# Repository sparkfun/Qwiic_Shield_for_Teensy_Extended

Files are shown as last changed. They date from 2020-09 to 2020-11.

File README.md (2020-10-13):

SparkFun Qwiic Shield for Teensy - Extended
========================================

SparkFun Qwiic Shield for Teensy

[SparkFun Qwiic Shield for Teensy (DEV-17156)](https://www.sparkfun.com/products/17156)

The SparkFun Qwiic Shield for Teensy connects the I<sup>2</sup>C bus on a Teensy-extended footprint (Teensy 4.1, 3.6, 3.5) to four Qwiic connectors as well as a "PROG" button in parallel with the Program button on the Teensy development board for easy access. The shield includes a set of headers to solder to the shield for connection to the Teensy.

Repository Contents
-------------------

* **/Documentation** - Board schematic (PDF) and dimensions (PNG & PDF)
* **/Hardware** - Eagle design files (.brd, .sch)

Documentation
--------------
* **[Hookup Guide](https://learn.sparkfun.com/tutorials/sparkfun-qwiic-shield-for-teensy-hookup-guide)** - Basic hookup guide for the SparkFun Qwiic Shield for Teensy - Extended

Version History
---------------
* **[DEV-17156](https://www.sparkfun.com/products/17156)** - Initial release.

License Information
-------------------

This product is _**open source**_! 

Please review the LICENSE.md file for license information. 

If you have any questions or concerns on licensing, please contact technical support on our [SparkFun forums](https://forum.sparkfun.com/viewforum.php?f=152).

Distributed as-is; no warranty is given.

- Your friends at SparkFun.

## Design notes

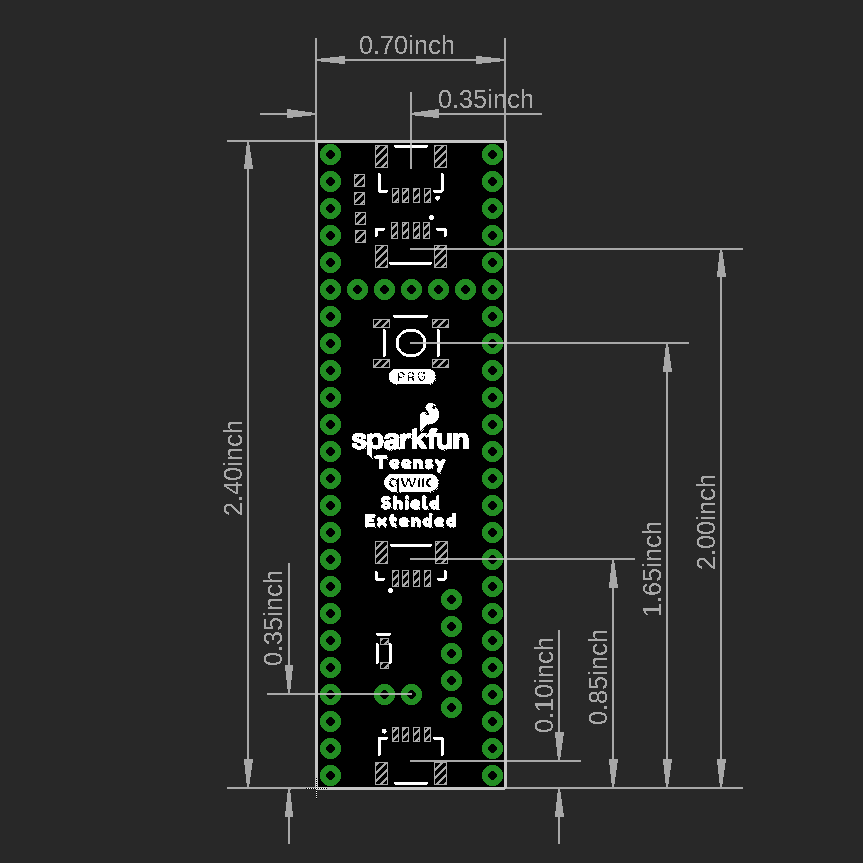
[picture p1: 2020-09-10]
Documents/Qwiic_Shield_for_Teensy_Extended_Dimensions.png

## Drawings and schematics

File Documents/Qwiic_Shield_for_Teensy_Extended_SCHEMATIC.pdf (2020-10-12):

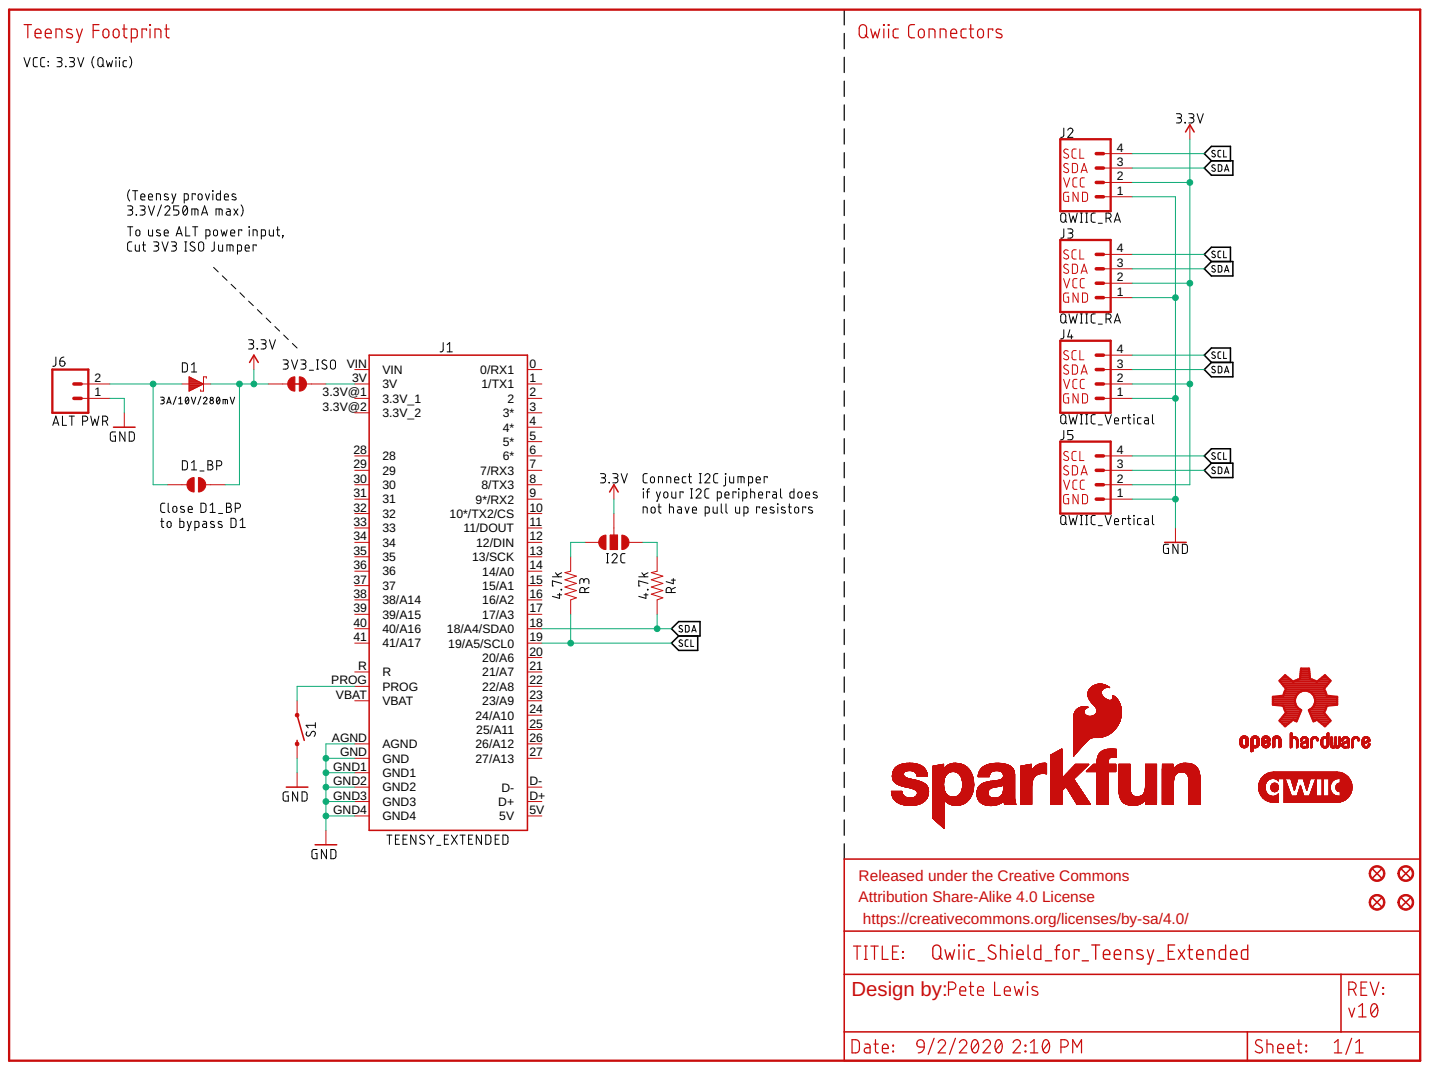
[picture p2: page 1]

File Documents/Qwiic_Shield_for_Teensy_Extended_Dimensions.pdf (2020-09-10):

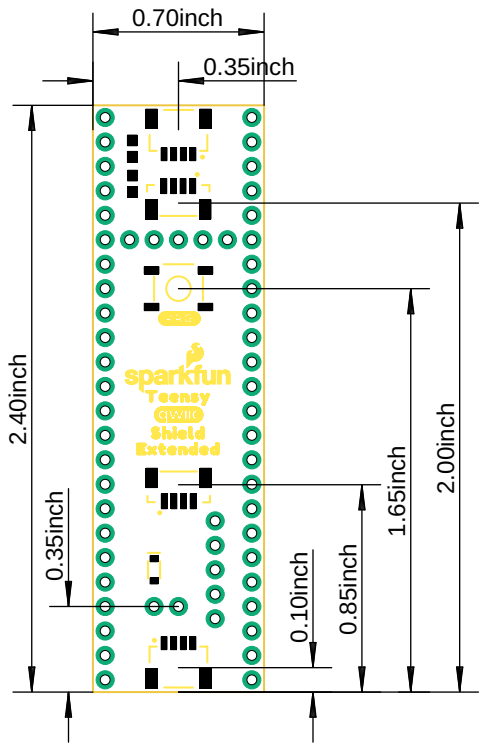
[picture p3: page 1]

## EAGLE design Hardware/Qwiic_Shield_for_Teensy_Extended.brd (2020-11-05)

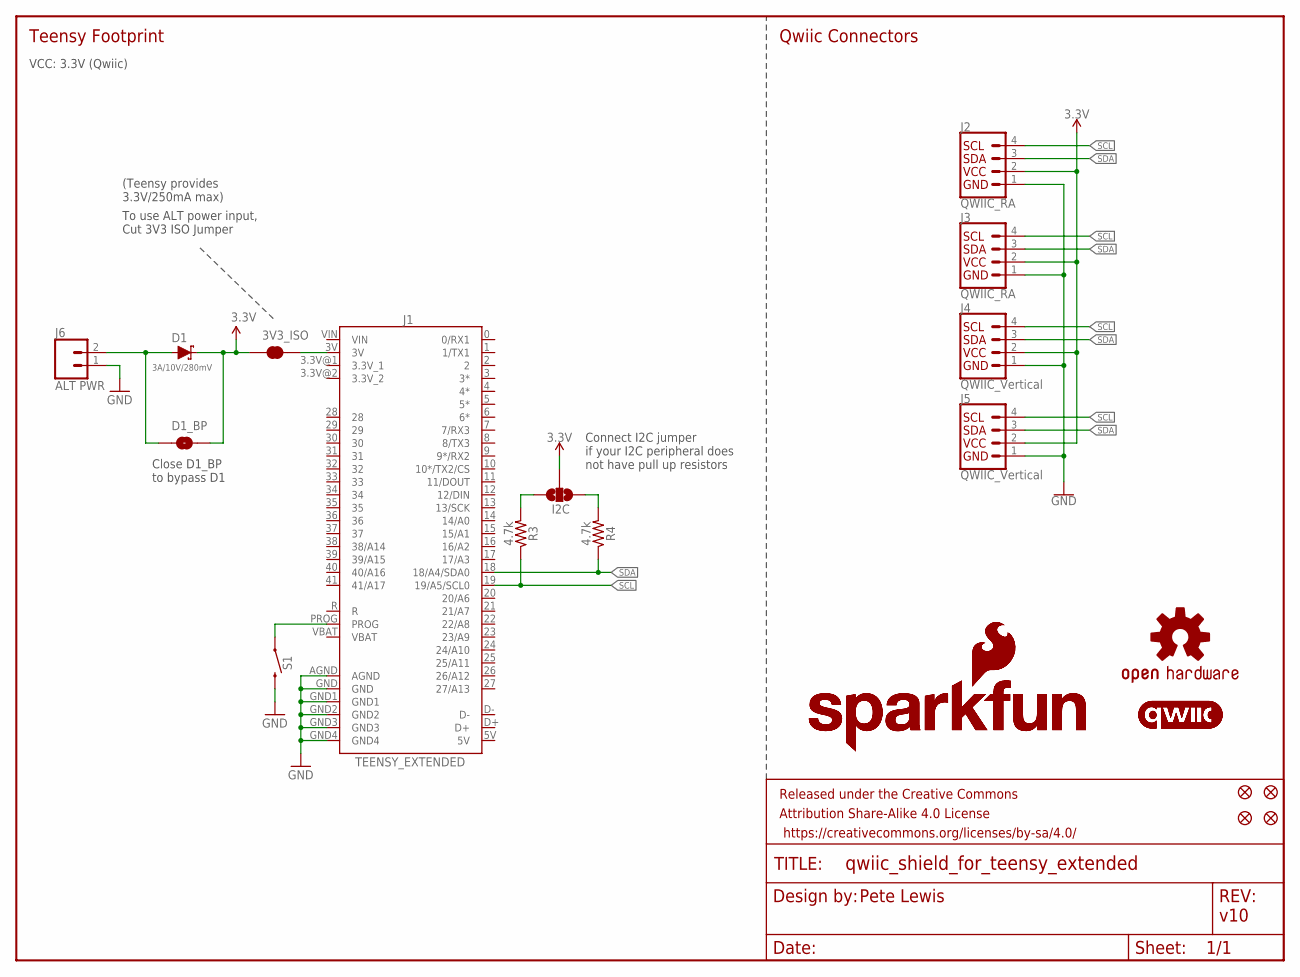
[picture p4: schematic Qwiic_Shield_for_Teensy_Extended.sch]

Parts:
3V3_ISO: JUMPER-SMT_2_NC_TRACE_SILK; SMT-JUMPER_2_NC_TRACE_SILK
D1: 3A/10V/280mV; SOD-323
D1_BP: JUMPER-SMT_2_NO_SILK; SMT-JUMPER_2_NO_SILK
FD1, FD2, FD3, FD4: FIDUCIAL1X2; FIDUCIAL-1X2
FRAME1: FRAME-LETTER; CREATIVE_COMMONS
I2C: JUMPER-SMT_3_NO_SILK; SMT-JUMPER_3_NO_SILK
J1: TEENSY_EXTENDED; TEENSY_EXTENDED_NO_SILK
J2, J3: QWIIC_RA; JST04_1MM_RA
J4, J5: QWIIC_Vertical; JST04_1MM_VERT
J6: ALT PWR; 1X02_NO_SILK
LOGO1, LOGO2: SFE_LOGO_NAME_FLAME.1_INCH; SFE_LOGO_NAME_FLAME_.1
LOGO3: OSHW-LOGOS; OSHW-LOGO-S
LOGO4, LOGO5: QWIIC_LOGO_5MM; QWIIC_5MM
R3, R4: 4.7k; 0603
S1: SMD_5.2MM; TACTILE_SWITCH_SMD_5.2MM

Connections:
3.3V: 3V3_ISO.1, D1.C, D1_BP.2, I2C.2, J2.2, J3.2, J4.2, J5.2
3.3V_1: J1.3.3V@1 (3.3V_1)
3.3V_2: J1.3.3V@2 (3.3V_2)
5V: J1.5V
D+: J1.D+
D-: J1.D-
GND: J1.AGND, J1.GND, J1.GND1, J1.GND2, J1.GND3, J1.GND4, J2.1, J3.1, J4.1, J5.1, J6.1, S1.3 (2)
unnamed: I2C.3, R4.2
unnamed: I2C.1, R3.2
unnamed: 3V3_ISO.2, J1.3V
unnamed: D1.A, D1_BP.1, J6.2
unnamed: J1.PROG, S1.1
SCL: J1.19 (19/A5/SCL0), J2.4, J3.4, J4.4, J5.4, R3.1
SDA: J1.18 (18/A4/SDA0), J2.3, J3.3, J4.3, J5.3, R4.1
VBAT: J1.VBAT
VIN: J1.VIN

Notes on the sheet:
Pete Lewis
v10
Teensy Footprint
Qwiic Connectors
VCC: 3.3V (Qwiic)
(Teensy provides 3.3V/250mA max)
Connect I2C jumper if your I2C peripheral does not have pull up resistors
To use ALT power input, Cut 3V3 ISO Jumper
Close D1_BP to bypass D1

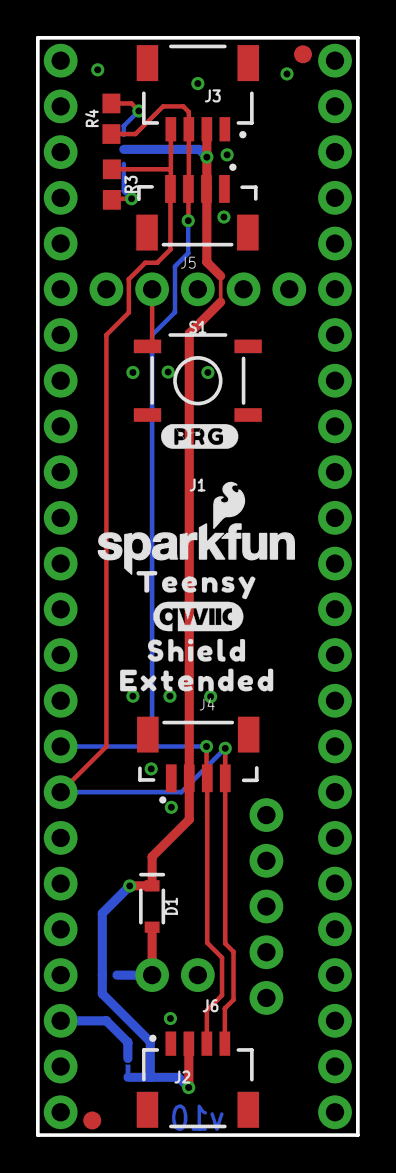
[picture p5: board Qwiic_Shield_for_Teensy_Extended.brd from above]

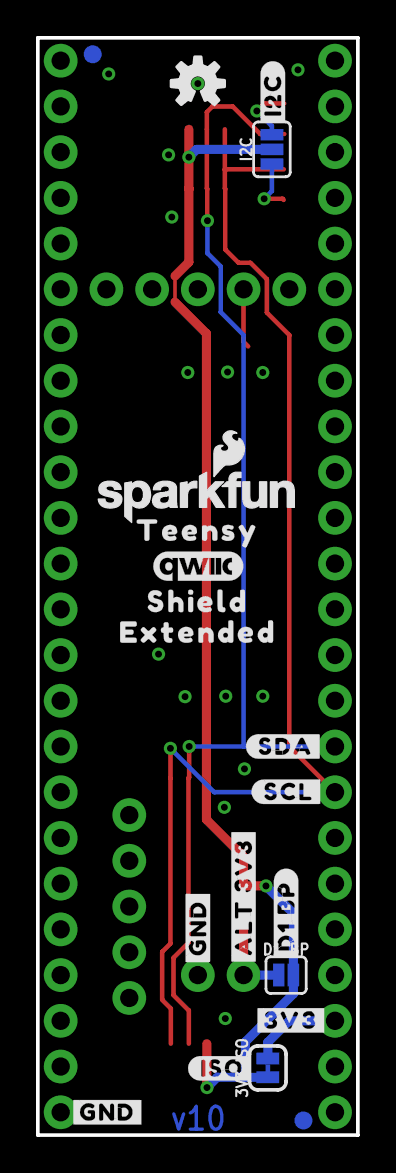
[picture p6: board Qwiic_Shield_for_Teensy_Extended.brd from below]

Board: 2 copper layers, 17.8 x 61.0 mm, 40 parts (20 on the bottom side), 9 nets.

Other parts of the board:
U$1: #I2C#0
U$2, U$13: TEENSY0
U$3: 3V36
U$4: #D1_BP#0
U$5: #ALT_3V3#0
U$6: #PRG#0
U$7, U$9: #GND#0
U$8, U$12: SHIELD0
U$10: #ISO#0
U$11, U$16: EXTENDED0
U$15: #3V3#0
U$18: #SDA#0
U$19: #SCL#0

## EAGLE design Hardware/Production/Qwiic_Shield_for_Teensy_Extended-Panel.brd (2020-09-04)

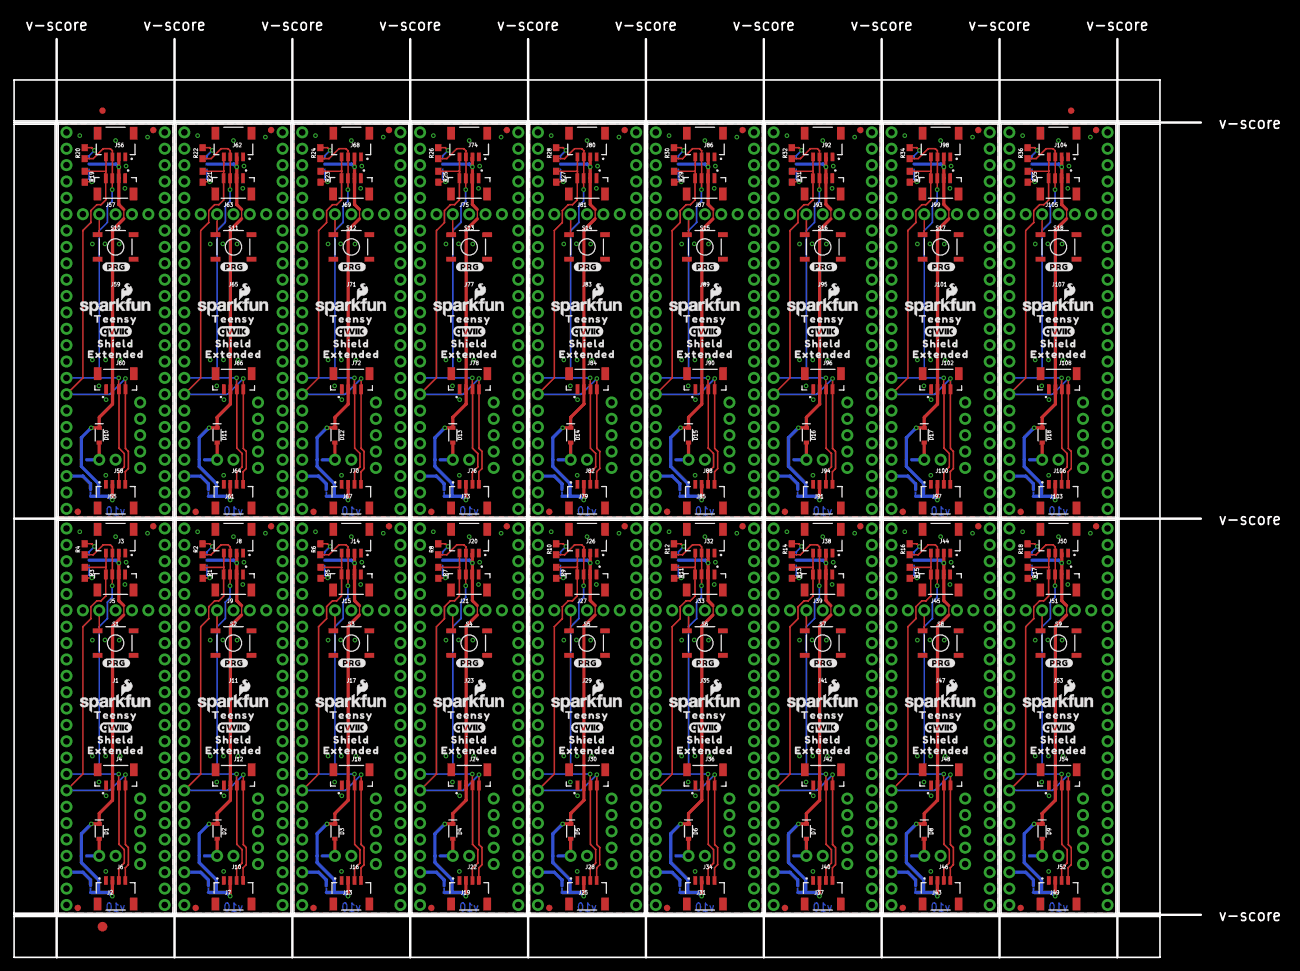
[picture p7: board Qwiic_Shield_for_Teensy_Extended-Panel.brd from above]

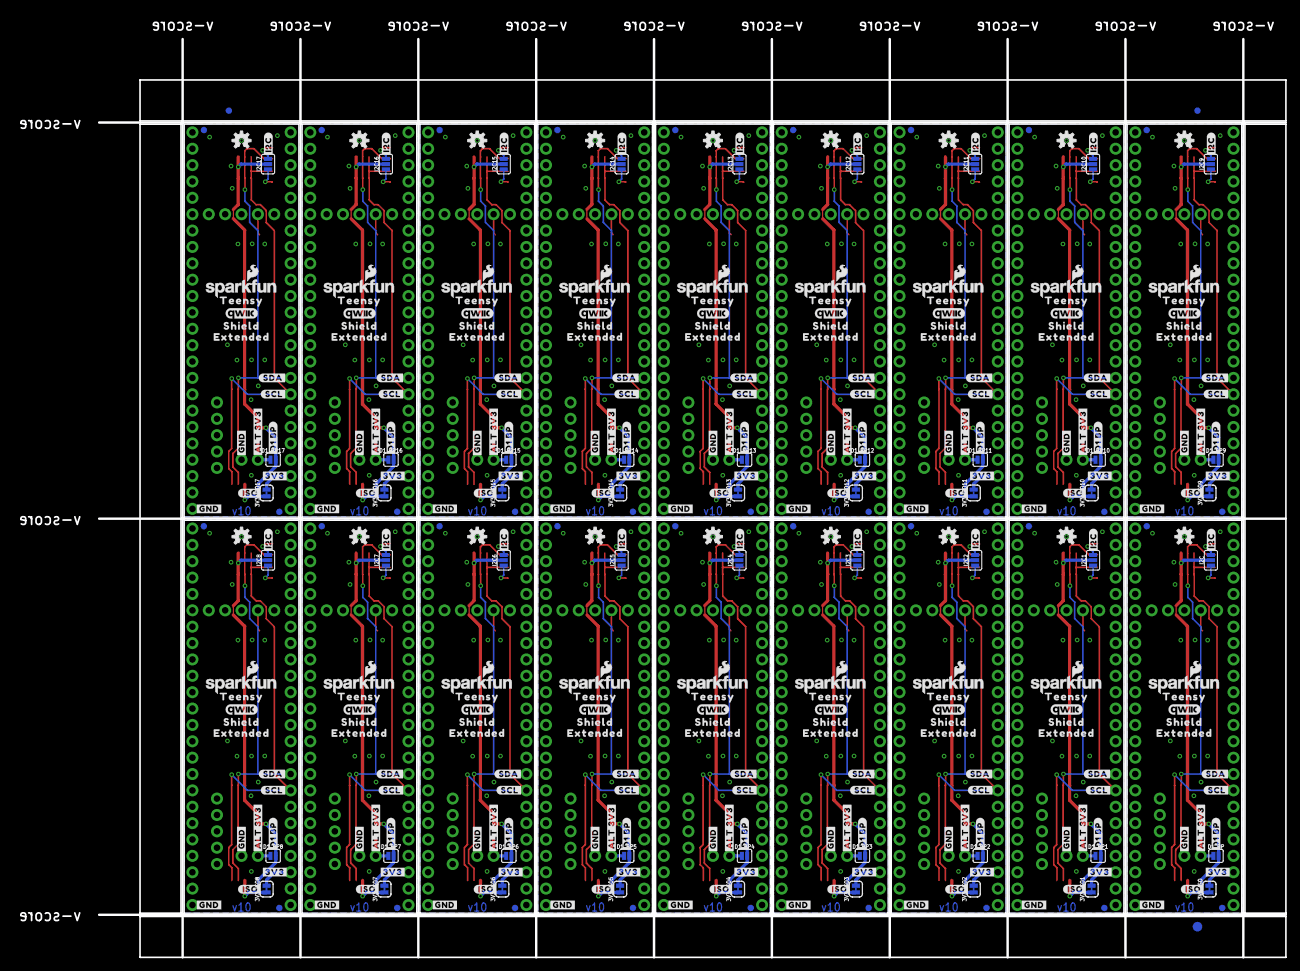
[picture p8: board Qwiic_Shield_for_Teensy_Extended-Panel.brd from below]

Board: 2 copper layers, 184.2 x 142.5 mm, 708 parts (363 on the bottom side), 162 nets.

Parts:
3V3_ISO, 3V3_ISO1, 3V3_ISO2, 3V3_ISO3, 3V3_ISO4, 3V3_ISO5, 3V3_ISO6, 3V3_ISO7, 3V3_ISO8, 3V3_ISO9, 3V3_ISO10, 3V3_ISO11, 3V3_ISO12, 3V3_ISO13, 3V3_ISO14, 3V3_ISO15, 3V3_ISO16, 3V3_ISO17: SMT-JUMPER_2_NC_TRACE_SILK
D1, D2, D3, D4, D5, D6, D7, D8, D9, D10, D11, D12, D13, D14, D15, D16, D17, D18: 3A/10V/280mV; SOD-323
D1_BP, D1_BP1, D1_BP2, D1_BP3, D1_BP4, D1_BP5, D1_BP6, D1_BP7, D1_BP8, D1_BP9, D1_BP10, D1_BP11, D1_BP12, D1_BP13, D1_BP14, D1_BP15, D1_BP16, D1_BP17: SMT-JUMPER_2_NO_SILK
E$1, E$2, E$3, E$4: FIDUCIAL-1X2
E$5, E$6: FIDUCIAL-1.5X3
FD1, FD2, FD3, FD4, FD5, FD6, FD7, FD8, FD9, FD10, FD11, FD12, FD13, FD14, FD15, FD16, FD17, FD18, FD19, FD20, FD21, FD22, FD23, FD24, FD25, FD26, FD27, FD28, FD29, FD30, FD31, FD32, FD33, FD34, FD35, FD36, FD37, FD38, FD39, FD40, FD41, FD42, FD43, FD44, FD45, FD46, FD47, FD48, FD49, FD50, FD51, FD52, FD53, FD54, FD55, FD56, FD57, FD58, FD59, FD60, FD61, FD62, FD63, FD64, FD65, FD66, FD67, FD68, FD69, FD70, FD71, FD72: FIDUCIAL1X2; FIDUCIAL-1X2
I2C, I2C1, I2C2, I2C3, I2C4, I2C5, I2C6, I2C7, I2C8, I2C9, I2C10, I2C11, I2C12, I2C13, I2C14, I2C15, I2C16, I2C17: JUMPER-SMT_3_NO_SILK; SMT-JUMPER_3_NO_SILK
J1, J11, J17, J23, J29, J35, J41, J47, J53, J59, J65, J71, J77, J83, J89, J95, J101, J107: TEENSY_EXTENDED; TEENSY_EXTENDED_NO_SILK
J2, J3, J7, J8, J13, J14, J19, J20, J25, J26, J31, J32, J37, J38, J43, J44, J49, J50, J55, J56, J61, J62, J67, J68, J73, J74, J79, J80, J85, J86, J91, J92, J97, J98, J103, J104: QWIIC_RA; JST04_1MM_RA
J4, J5, J9, J12, J15, J18, J21, J24, J27, J30, J33, J36, J39, J42, J45, J48, J51, J54, J57, J60, J63, J66, J69, J72, J75, J78, J81, J84, J87, J90, J93, J96, J99, J102, J105, J108: QWIIC_Vertical; JST04_1MM_VERT
J6, J10, J16, J22, J28, J34, J40, J46, J52, J58, J64, J70, J76, J82, J88, J94, J100, J106: ALT PWR; 1X02_NO_SILK
LOGO1, LOGO2, LOGO6, LOGO9, LOGO11, LOGO14, LOGO16, LOGO19, LOGO21, LOGO24, LOGO26, LOGO29, LOGO31, LOGO34, LOGO36, LOGO39, LOGO41, LOGO44, LOGO46, LOGO49, LOGO51, LOGO54, LOGO56, LOGO59, LOGO61, LOGO64, LOGO66, LOGO69, LOGO71, LOGO74, LOGO76, LOGO79, LOGO81, LOGO84, LOGO86, LOGO89: SFE_LOGO_NAME_FLAME.1_INCH; SFE_LOGO_NAME_FLAME_.1
LOGO3, LOGO7, LOGO12, LOGO17, LOGO22, LOGO27, LOGO32, LOGO37, LOGO42, LOGO47, LOGO52, LOGO57, LOGO62, LOGO67, LOGO72, LOGO77, LOGO82, LOGO87: OSHW-LOGOS; OSHW-LOGO-S
LOGO4, LOGO5, LOGO8, LOGO10, LOGO13, LOGO15, LOGO18, LOGO20, LOGO23, LOGO25, LOGO28, LOGO30, LOGO33, LOGO35, LOGO38, LOGO40, LOGO43, LOGO45, LOGO48, LOGO50, LOGO53, LOGO55, LOGO58, LOGO60, LOGO63, LOGO65, LOGO68, LOGO70, LOGO73, LOGO75, LOGO78, LOGO80, LOGO83, LOGO85, LOGO88, LOGO90: QWIIC_LOGO_5MM; QWIIC_5MM
R1, R2, R3, R4, R5, R6, R7, R8, R9, R10, R11, R12, R13, R14, R15, R16, R17, R18, R19, R20, R21, R22, R23, R24, R25, R26, R27, R28, R29, R30, R31, R32, R33, R34, R35, R36: 4.7k; 0603
S1, S2, S3, S4, S5, S6, S7, S8, S9, S10, S11, S12, S13, S14, S15, S16, S17, S18: SMD_5.2MM; TACTILE_SWITCH_SMD_5.2MM
U$1, U$23, U$40, U$57, U$74, U$91, U$108, U$125, U$142, U$159, U$176, U$193, U$210, U$227, U$244, U$261, U$278, U$295: #I2C#0
U$2, U$13, U$17, U$30, U$36, U$47, U$53, U$64, U$70, U$81, U$87, U$98, U$104, U$115, U$121, U$132, U$138, U$149, U$155, U$166, U$172, U$183, U$189, U$200, U$206, U$217, U$223, U$234, U$240, U$251, U$257, U$268, U$274, U$285, U$291, U$302: TEENSY0
U$3, U$14, U$35, U$52, U$69, U$86, U$103, U$120, U$137, U$154, U$171, U$188, U$205, U$222, U$239, U$256, U$273, U$290: 3V36
U$4, U$24, U$41, U$58, U$75, U$92, U$109, U$126, U$143, U$160, U$177, U$194, U$211, U$228, U$245, U$262, U$279, U$296: #D1_BP#0
U$5, U$25, U$42, U$59, U$76, U$93, U$110, U$127, U$144, U$161, U$178, U$195, U$212, U$229, U$246, U$263, U$280, U$297: #ALT_3V3#0
U$6, U$28, U$45, U$62, U$79, U$96, U$113, U$130, U$147, U$164, U$181, U$198, U$215, U$232, U$249, U$266, U$283, U$300: #PRG#0
U$7, U$9, U$26, U$32, U$43, U$49, U$60, U$66, U$77, U$83, U$94, U$100, U$111, U$117, U$128, U$134, U$145, U$151, U$162, U$168, U$179, U$185, U$196, U$202, U$213, U$219, U$230, U$236, U$247, U$253, U$264, U$270, U$281, U$287, U$298, U$304: #GND#0
U$8, U$12, U$27, U$31, U$44, U$48, U$61, U$65, U$78, U$82, U$95, U$99, U$112, U$116, U$129, U$133, U$146, U$150, U$163, U$167, U$180, U$184, U$197, U$201, U$214, U$218, U$231, U$235, U$248, U$252, U$265, U$269, U$282, U$286, U$299, U$303: SHIELD0
U$10, U$29, U$46, U$63, U$80, U$97, U$114, U$131, U$148, U$165, U$182, U$199, U$216, U$233, U$250, U$267, U$284, U$301: #ISO#0
U$11, U$16, U$33, U$34, U$50, U$51, U$67, U$68, U$84, U$85, U$101, U$102, U$118, U$119, U$135, U$136, U$152, U$153, U$169, U$170, U$186, U$187, U$203, U$204, U$220, U$221, U$237, U$238, U$254, U$255, U$271, U$272, U$288, U$289, U$305, U$306: EXTENDED0
U$15, U$20, U$37, U$54, U$71, U$88, U$105, U$122, U$139, U$156, U$173, U$190, U$207, U$224, U$241, U$258, U$275, U$292: #3V3#0
U$18, U$21, U$38, U$55, U$72, U$89, U$106, U$123, U$140, U$157, U$174, U$191, U$208, U$225, U$242, U$259, U$276, U$293: #SDA#0
U$19, U$22, U$39, U$56, U$73, U$90, U$107, U$124, U$141, U$158, U$175, U$192, U$209, U$226, U$243, U$260, U$277, U$294: #SCL#0

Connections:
3.3V: 3V3_ISO.1, D1.C, D1_BP.2, I2C.2, J2.2, J3.2, J4.2, J5.2
3.3V1: 3V3_ISO1.1, D1_BP1.2, D2.C, I2C1.2, J7.2, J8.2, J9.2, J12.2
3.3V2: 3V3_ISO2.1, D1_BP2.2, D3.C, I2C2.2, J13.2, J14.2, J15.2, J18.2
3.3V3: 3V3_ISO3.1, D1_BP3.2, D4.C, I2C3.2, J19.2, J20.2, J21.2, J24.2
3.3V4: 3V3_ISO4.1, D1_BP4.2, D5.C, I2C4.2, J25.2, J26.2, J27.2, J30.2
3.3V5: 3V3_ISO5.1, D1_BP5.2, D6.C, I2C5.2, J31.2, J32.2, J33.2, J36.2
3.3V6: 3V3_ISO6.1, D1_BP6.2, D7.C, I2C6.2, J37.2, J38.2, J39.2, J42.2
3.3V7: 3V3_ISO7.1, D1_BP7.2, D8.C, I2C7.2, J43.2, J44.2, J45.2, J48.2
3.3V8: 3V3_ISO8.1, D1_BP8.2, D9.C, I2C8.2, J49.2, J50.2, J51.2, J54.2
3.3V9: 3V3_ISO9.1, D1_BP9.2, D10.C, I2C9.2, J55.2, J56.2, J57.2, J60.2
3.3V10: 3V3_ISO10.1, D1_BP10.2, D11.C, I2C10.2, J61.2, J62.2, J63.2, J66.2
3.3V11: 3V3_ISO11.1, D1_BP11.2, D12.C, I2C11.2, J67.2, J68.2, J69.2, J72.2
3.3V12: 3V3_ISO12.1, D1_BP12.2, D13.C, I2C12.2, J73.2, J74.2, J75.2, J78.2
3.3V13: 3V3_ISO13.1, D1_BP13.2, D14.C, I2C13.2, J79.2, J80.2, J81.2, J84.2
3.3V14: 3V3_ISO14.1, D1_BP14.2, D15.C, I2C14.2, J85.2, J86.2, J87.2, J90.2
3.3V15: 3V3_ISO15.1, D1_BP15.2, D16.C, I2C15.2, J91.2, J92.2, J93.2, J96.2
3.3V16: 3V3_ISO16.1, D1_BP16.2, D17.C, I2C16.2, J97.2, J98.2, J99.2, J102.2
3.3V17: 3V3_ISO17.1, D1_BP17.2, D18.C, I2C17.2, J103.2, J104.2, J105.2, J108.2
GND: J1.AGND, J1.GND, J1.GND1, J1.GND2, J1.GND3, J1.GND4, J2.1, J3.1, J4.1, J5.1, J6.1, S1.3
GND1: J7.1, J8.1, J9.1, J10.1, J11.AGND, J11.GND, J11.GND1, J11.GND2, J11.GND3, J11.GND4, J12.1, S2.3
GND2: J13.1, J14.1, J15.1, J16.1, J17.AGND, J17.GND, J17.GND1, J17.GND2, J17.GND3, J17.GND4, J18.1, S3.3
GND3: J19.1, J20.1, J21.1, J22.1, J23.AGND, J23.GND, J23.GND1, J23.GND2, J23.GND3, J23.GND4, J24.1, S4.3
GND4: J25.1, J26.1, J27.1, J28.1, J29.AGND, J29.GND, J29.GND1, J29.GND2, J29.GND3, J29.GND4, J30.1, S5.3
GND5: J31.1, J32.1, J33.1, J34.1, J35.AGND, J35.GND, J35.GND1, J35.GND2, J35.GND3, J35.GND4, J36.1, S6.3
GND6: J37.1, J38.1, J39.1, J40.1, J41.AGND, J41.GND, J41.GND1, J41.GND2, J41.GND3, J41.GND4, J42.1, S7.3
GND7: J43.1, J44.1, J45.1, J46.1, J47.AGND, J47.GND, J47.GND1, J47.GND2, J47.GND3, J47.GND4, J48.1, S8.3
GND8: J49.1, J50.1, J51.1, J52.1, J53.AGND, J53.GND, J53.GND1, J53.GND2, J53.GND3, J53.GND4, J54.1, S9.3
GND9: J55.1, J56.1, J57.1, J58.1, J59.AGND, J59.GND, J59.GND1, J59.GND2, J59.GND3, J59.GND4, J60.1, S10.3
GND10: J61.1, J62.1, J63.1, J64.1, J65.AGND, J65.GND, J65.GND1, J65.GND2, J65.GND3, J65.GND4, J66.1, S11.3
GND11: J67.1, J68.1, J69.1, J70.1, J71.AGND, J71.GND, J71.GND1, J71.GND2, J71.GND3, J71.GND4, J72.1, S12.3
GND12: J73.1, J74.1, J75.1, J76.1, J77.AGND, J77.GND, J77.GND1, J77.GND2, J77.GND3, J77.GND4, J78.1, S13.3
GND13: J79.1, J80.1, J81.1, J82.1, J83.AGND, J83.GND, J83.GND1, J83.GND2, J83.GND3, J83.GND4, J84.1, S14.3
GND14: J85.1, J86.1, J87.1, J88.1, J89.AGND, J89.GND, J89.GND1, J89.GND2, J89.GND3, J89.GND4, J90.1, S15.3
GND15: J91.1, J92.1, J93.1, J94.1, J95.AGND, J95.GND, J95.GND1, J95.GND2, J95.GND3, J95.GND4, J96.1, S16.3
GND16: J97.1, J98.1, J99.1, J100.1, J101.AGND, J101.GND, J101.GND1, J101.GND2, J101.GND3, J101.GND4, J102.1, S17.3
GND17: J103.1, J104.1, J105.1, J106.1, J107.AGND, J107.GND, J107.GND1, J107.GND2, J107.GND3, J107.GND4, J108.1, S18.3
unnamed: I2C.3, R4.2
unnamed: I2C.1, R3.2
unnamed: 3V3_ISO.2, J1.3V
unnamed: D1.A, D1_BP.1, J6.2
unnamed: J1.PROG, S1.1
unnamed: I2C1.3, R2.2
unnamed: I2C1.1, R1.2
unnamed: D1_BP1.1, D2.A, J10.2
unnamed: J11.PROG, S2.1
unnamed: 3V3_ISO1.2, J11.3V
unnamed: I2C2.3, R6.2
unnamed: I2C2.1, R5.2
unnamed: D1_BP2.1, D3.A, J16.2
unnamed: J17.PROG, S3.1
unnamed: 3V3_ISO2.2, J17.3V
unnamed: I2C3.3, R8.2
unnamed: I2C3.1, R7.2
unnamed: D1_BP3.1, D4.A, J22.2
unnamed: J23.PROG, S4.1
unnamed: 3V3_ISO3.2, J23.3V
unnamed: I2C4.3, R10.2
unnamed: I2C4.1, R9.2
unnamed: D1_BP4.1, D5.A, J28.2
unnamed: J29.PROG, S5.1
unnamed: 3V3_ISO4.2, J29.3V
unnamed: I2C5.3, R12.2
unnamed: I2C5.1, R11.2
unnamed: D1_BP5.1, D6.A, J34.2
unnamed: J35.PROG, S6.1
unnamed: 3V3_ISO5.2, J35.3V
unnamed: I2C6.3, R14.2
unnamed: I2C6.1, R13.2
unnamed: D1_BP6.1, D7.A, J40.2
unnamed: J41.PROG, S7.1
unnamed: 3V3_ISO6.2, J41.3V
unnamed: I2C7.3, R16.2
unnamed: I2C7.1, R15.2
unnamed: D1_BP7.1, D8.A, J46.2
unnamed: J47.PROG, S8.1
unnamed: 3V3_ISO7.2, J47.3V
unnamed: I2C8.3, R18.2
unnamed: I2C8.1, R17.2
unnamed: D1_BP8.1, D9.A, J52.2
unnamed: J53.PROG, S9.1
unnamed: 3V3_ISO8.2, J53.3V
unnamed: I2C9.3, R20.2
unnamed: I2C9.1, R19.2
unnamed: D1_BP9.1, D10.A, J58.2
unnamed: J59.PROG, S10.1
unnamed: 3V3_ISO9.2, J59.3V
unnamed: I2C10.3, R22.2
unnamed: I2C10.1, R21.2
unnamed: D1_BP10.1, D11.A, J64.2
unnamed: J65.PROG, S11.1
unnamed: 3V3_ISO10.2, J65.3V
unnamed: I2C11.3, R24.2
unnamed: I2C11.1, R23.2
unnamed: D1_BP11.1, D12.A, J70.2
unnamed: J71.PROG, S12.1
unnamed: 3V3_ISO11.2, J71.3V
unnamed: I2C12.3, R26.2
unnamed: I2C12.1, R25.2
unnamed: D1_BP12.1, D13.A, J76.2
unnamed: J77.PROG, S13.1
unnamed: 3V3_ISO12.2, J77.3V
unnamed: I2C13.3, R28.2
unnamed: I2C13.1, R27.2
unnamed: D1_BP13.1, D14.A, J82.2
unnamed: J83.PROG, S14.1
unnamed: 3V3_ISO13.2, J83.3V
unnamed: I2C14.3, R30.2
unnamed: I2C14.1, R29.2
unnamed: D1_BP14.1, D15.A, J88.2
unnamed: J89.PROG, S15.1
unnamed: 3V3_ISO14.2, J89.3V
unnamed: I2C15.3, R32.2
unnamed: I2C15.1, R31.2
unnamed: D1_BP15.1, D16.A, J94.2
unnamed: J95.PROG, S16.1
unnamed: 3V3_ISO15.2, J95.3V
unnamed: I2C16.3, R34.2
unnamed: I2C16.1, R33.2
unnamed: D1_BP16.1, D17.A, J100.2
unnamed: J101.PROG, S17.1
unnamed: 3V3_ISO16.2, J101.3V
unnamed: I2C17.3, R36.2
unnamed: I2C17.1, R35.2
unnamed: D1_BP17.1, D18.A, J106.2
unnamed: J107.PROG, S18.1
unnamed: 3V3_ISO17.2, J107.3V
SCL: J1.19, J2.4, J3.4, J4.4, J5.4, R3.1
SCL1: J7.4, J8.4, J9.4, J11.19, J12.4, R1.1
SCL2: J13.4, J14.4, J15.4, J17.19, J18.4, R5.1
SCL3: J19.4, J20.4, J21.4, J23.19, J24.4, R7.1
SCL4: J25.4, J26.4, J27.4, J29.19, J30.4, R9.1
SCL5: J31.4, J32.4, J33.4, J35.19, J36.4, R11.1
SCL6: J37.4, J38.4, J39.4, J41.19, J42.4, R13.1
SCL7: J43.4, J44.4, J45.4, J47.19, J48.4, R15.1
SCL8: J49.4, J50.4, J51.4, J53.19, J54.4, R17.1
SCL9: J55.4, J56.4, J57.4, J59.19, J60.4, R19.1
SCL10: J61.4, J62.4, J63.4, J65.19, J66.4, R21.1
SCL11: J67.4, J68.4, J69.4, J71.19, J72.4, R23.1
SCL12: J73.4, J74.4, J75.4, J77.19, J78.4, R25.1
SCL13: J79.4, J80.4, J81.4, J83.19, J84.4, R27.1
SCL14: J85.4, J86.4, J87.4, J89.19, J90.4, R29.1
SCL15: J91.4, J92.4, J93.4, J95.19, J96.4, R31.1
SCL16: J97.4, J98.4, J99.4, J101.19, J102.4, R33.1
SCL17: J103.4, J104.4, J105.4, J107.19, J108.4, R35.1
SDA: J1.18, J2.3, J3.3, J4.3, J5.3, R4.1
SDA1: J7.3, J8.3, J9.3, J11.18, J12.3, R2.1
SDA2: J13.3, J14.3, J15.3, J17.18, J18.3, R6.1
SDA3: J19.3, J20.3, J21.3, J23.18, J24.3, R8.1
SDA4: J25.3, J26.3, J27.3, J29.18, J30.3, R10.1
SDA5: J31.3, J32.3, J33.3, J35.18, J36.3, R12.1
SDA6: J37.3, J38.3, J39.3, J41.18, J42.3, R14.1
SDA7: J43.3, J44.3, J45.3, J47.18, J48.3, R16.1
SDA8: J49.3, J50.3, J51.3, J53.18, J54.3, R18.1
SDA9: J55.3, J56.3, J57.3, J59.18, J60.3, R20.1
SDA10: J61.3, J62.3, J63.3, J65.18, J66.3, R22.1
SDA11: J67.3, J68.3, J69.3, J71.18, J72.3, R24.1
SDA12: J73.3, J74.3, J75.3, J77.18, J78.3, R26.1
SDA13: J79.3, J80.3, J81.3, J83.18, J84.3, R28.1
SDA14: J85.3, J86.3, J87.3, J89.18, J90.3, R30.1
SDA15: J91.3, J92.3, J93.3, J95.18, J96.3, R32.1
SDA16: J97.3, J98.3, J99.3, J101.18, J102.3, R34.1
SDA17: J103.3, J104.3, J105.3, J107.18, J108.3, R36.1

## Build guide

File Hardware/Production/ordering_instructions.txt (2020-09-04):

panel size, 178x130mm
PCB thickness, 1.6mm
number of layers, 2
soldermask color, Red
silkscreen color, White
oz copper, 1oz
finish, HASL lead free
stencils, top
pcs per panel, 18
min trace width, 0.2032mm / 0.0080in
min drill size, 0.3810mm / 0.0150in

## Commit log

2020-09-02 separating design into "normal" and extended version with separate repos
    [Qwiic_Shield_for_Teensy_Extended.brd, Qwiic_Shield_for_Teensy_Extended.sch]
2020-09-02 checklist run post design review
    -adjusted values for better assembly sheet
    [Qwiic_Shield_for_Teensy_Extended.brd, Qwiic_Shield_for_Teensy_Extended.sch]
2020-09-03 Measures correction
    -removed old measures that were left over from short version
    -straightened the measure for the middle-bottom qwiic connector that was ever so slightly off.
    [Qwiic_Shield_for_Teensy_Extended.brd]
2020-09-04 Production panel v10
    [Qwiic_Shield_for_Teensy_Extended-Panel.GBL, Qwiic_Shield_for_Teensy_Extended-Panel.GBO, Qwiic_Shield_for_Teensy_Extended-Panel.GBP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]
2020-09-10 Dimensional drawings
    -also added a couplt more measures to brd file
    [Qwiic_Shield_for_Teensy_Extended.brd]
2020-11-05 migrated teensy part to SparkFun-Boards.lbr
    [Qwiic_Shield_for_Teensy_Extended.brd, Qwiic_Shield_for_Teensy_Extended.sch]

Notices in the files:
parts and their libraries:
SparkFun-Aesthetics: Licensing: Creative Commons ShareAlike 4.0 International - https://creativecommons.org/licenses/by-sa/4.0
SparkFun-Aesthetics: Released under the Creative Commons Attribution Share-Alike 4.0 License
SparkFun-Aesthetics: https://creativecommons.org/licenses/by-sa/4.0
